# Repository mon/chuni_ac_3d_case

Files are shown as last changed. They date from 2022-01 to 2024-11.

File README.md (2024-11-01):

# Chunithm 3D printed case

This is a 3D printed case so your slider panel + airs you bought off Yahoo
Auctions can happily sit on a table.

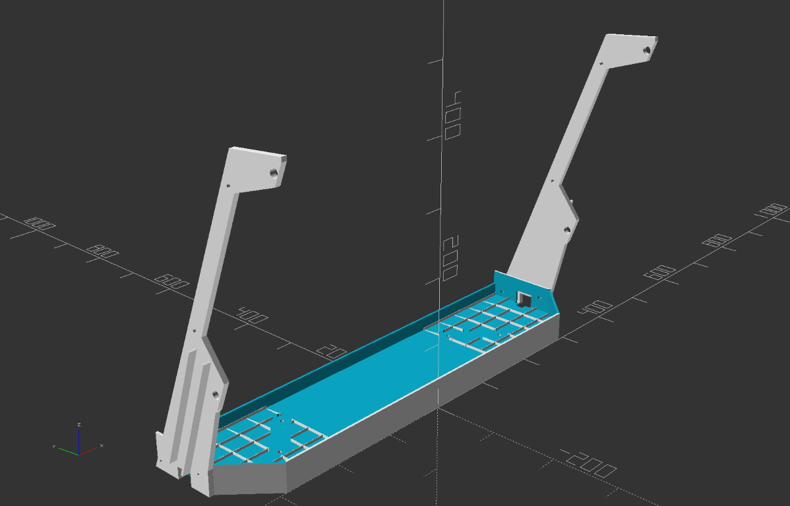
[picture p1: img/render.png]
Render

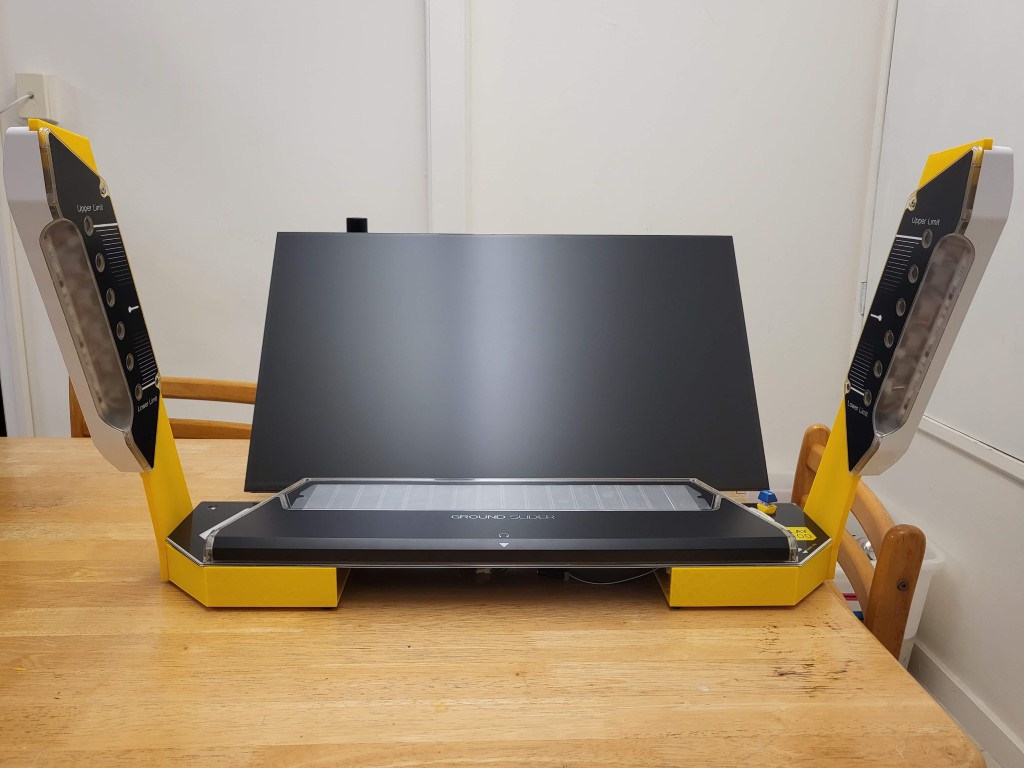
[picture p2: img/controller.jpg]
IRL photo


## Print settings
For all pieces, I used 10% infill, no supports, 0.28mm layer height (Cura's
"Low quality" setting).

## Installation
You will need
- M4 bolt x4, 14mm or longer
- M4 washer x4
- M4 nut x4
- M5 bolt x4, 6mm or longer (these may already exist in the black metal brackets
  the airs were originally attached to)
- Soldering iron or hot object (to press-fit M4 nuts into 3D print)
- About 600g of filament
- 8 rubber adhesive feet

Print all the pieces in the `stl` folder. Ignore `coin_return_cherry_mx` if
you're not going to use it. The `air_bottom` piece will need to be flipped in
your slicer so the flat side is on the bed. Also, mirror `air_bottom` and print
another copy for the opposite air. Ignore `air_bottom` and `air_top` if you want to
lasercut the airs.

Disassemble your air strings, making note of the 2 shorter bolts on the front
side. Put the printed pieces in and reinstall screws. DO NOT OVER-TIGHTEN. The
plastic of the airs may crack if you do. You might need to gently bend the wire
harness to comfortably make it into the wire channel, this is normal.

Using a soldering iron to heat the M4 nuts, carefully push them into the holes on
the case parts. You're not looking for a structural fit, it's just so
the nuts don't fall out.

Attach the rubber feet to the bottom of the case so the screws don't scratch
your table.

You can install the case first or attach the airs to the case first, I prefer
attaching the airs because routing the cable is easier.

Use the M4 bolts and washers to attach the air strings to the case.

Use the M5 bolts to attach the case to the metal bracket on the back of the
slider.

Hook up wiring (see the [wiki](https://rhythm-cons.wiki/w/Chunithm)).

## Notes
- The print is designed for a bed of 300mm, e.g. a CR10s. With some creative
  cutting, it could be fit into a 200mm bed. Feel free to submit a PR if you
  work it out.
- The print contains very large, flat sections directly on the bed. If you don't
  have a flat bed or a mesh bed level, it WILL warp. This can result in
  dimensional inaccuracy (not a huge problem really) or part detachment
  mid-print (quite a problem).
- Some of the holes are off by 0.5-1mm, but it doesn't affect installation. You
  can fix it if you're a perfectionist.

## Thanks
To Moldypie, for the original laser-cut case. The airs would have not existed
without it.

## SCAD notes
It's a mess. Made in a rush, and probably incomprehensible to anyone but me.
Mixture of constants in good places and magic numbers in other places.

Modify `op` at the bottom of the file to render different parts of the build.

Gratuitously use `#` and `%` to debug things if you're trying to extend it.

# Cherry MX adapter for coin return
Bonus!

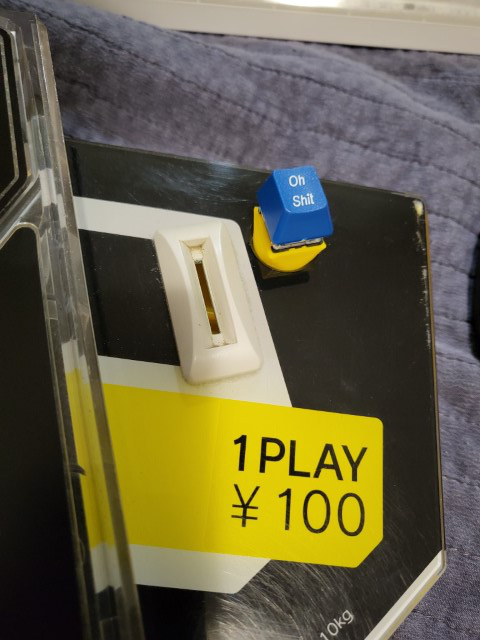
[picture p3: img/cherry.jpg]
Cherry adapter


This lets you replace the coin return button with a Cherry MX switch. Solder
leads to it and pass them through the middle.

I printed this using 0.2mm layer height and used the original nut and washer
to attach it to the metal. It was _extremely_ tight, so I recommend playing with
the tolerances in the thread library if you don't want to get out two spanners
and potentially shatter the piece.

## Lasercuttable Airs

If you don't have a big enough printer or want to make the airs out of another material.

Lasercut `air_lasercut` in the `dxfs` folder with 8mm thick material.
**DO NOT USE** `wall 1_flat` due to bad hole locations.

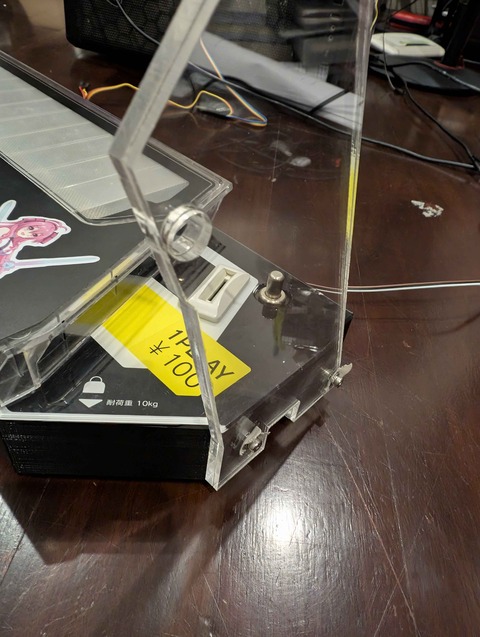
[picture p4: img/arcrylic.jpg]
arcrylic air


I used a combination of 5mm and 3mm arcrylic to make it 8mm thick.

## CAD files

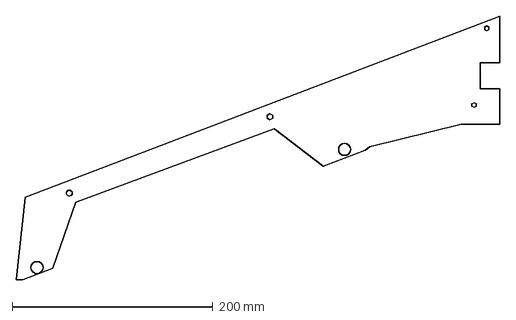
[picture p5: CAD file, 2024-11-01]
dxfs/air_lasercut.dxf
480.8 x 262.2 mm

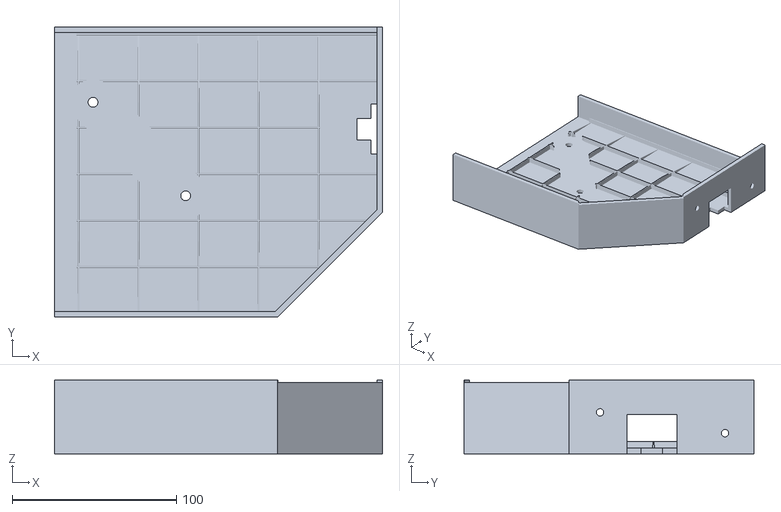
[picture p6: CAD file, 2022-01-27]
stls/case_right.stl
200.0 x 177.0 x 45.1

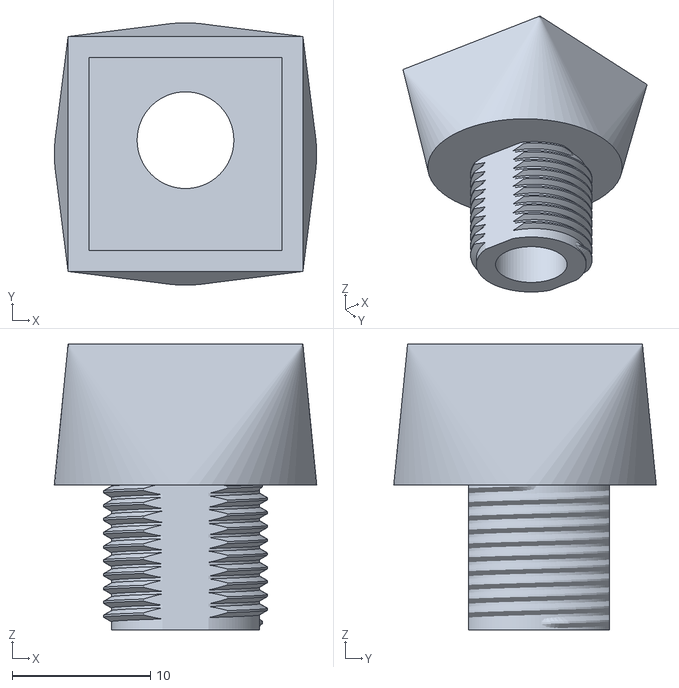
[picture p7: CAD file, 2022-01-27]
stls/coin_return_cherry_mx.stl
19.0 x 19.0 x 20.7

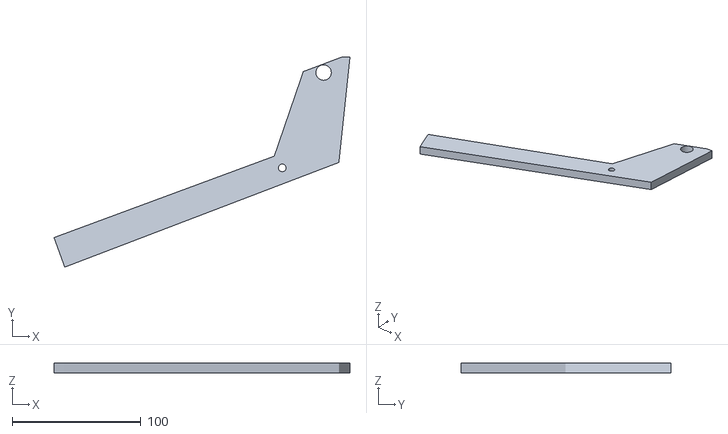
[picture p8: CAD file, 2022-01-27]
stls/air_top.stl
229.7 x 163.2 x 8.00

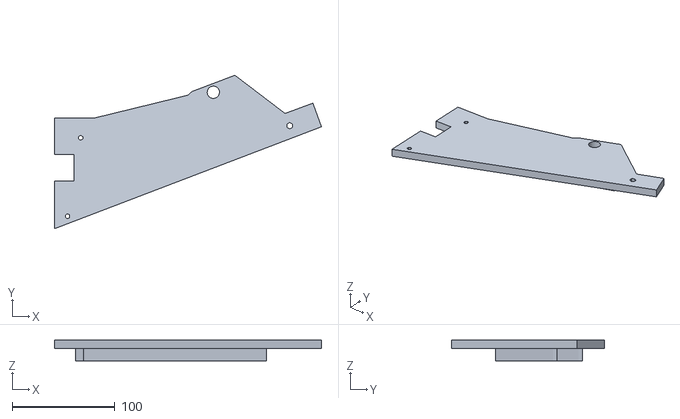
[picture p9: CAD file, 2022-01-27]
stls/air_bottom.stl
259.4 x 149.1 x 20.0

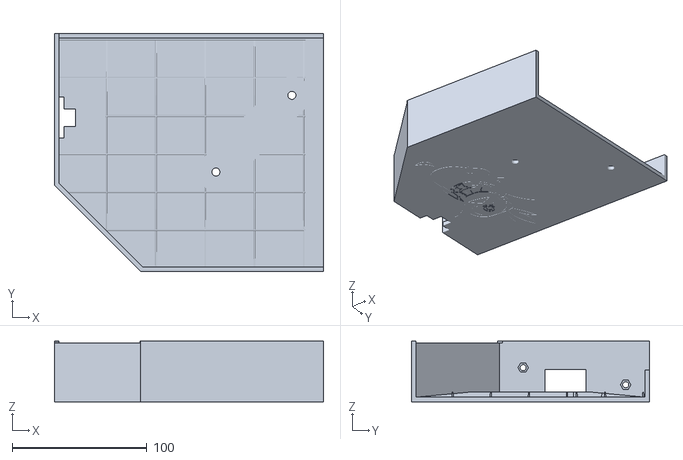
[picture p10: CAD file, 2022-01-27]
stls/case_left.stl
200.0 x 177.0 x 45.1

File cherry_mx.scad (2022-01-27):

$fn=60;
/**
a cherry mx switch.

most of the measurements done with a caliper. some taken from
http://geekhack.org/index.php?topic=47744.0

This is just to illustrate and to drop in a a gross reference. It is mostly artistic apart from the steam and mounting plate dimensions
*/

module cherry_mx_model() {

    translate([0,0,14.85])
    {

        //1. steam
        color("brown"){
            //1.1. l-r tab is 1.35mm
            translate([0,0,-3.62/2])
                cube([1.35,4.5,3.62], center=true);
            //1.2. f-b tab is 1.15mm. it has a smal notch that i will ignore.
            translate([0,0,-3.62/2])
                cube([4.5,1.15,3.62], center=true);
            //1.3. base. it has a chamfered top that i will ignore.
            translate([0,0,-5.62])
                cube([7.2,5.56,4], center=true);
        }
        // 2. top
        color("grey"){
            difference(){
                // make a trapezoid with the general shape (volume?) of the top
                hull(){
                    translate([0,0,-4]) //distance from top of switch... some i measured 3.9 others 4.2... so leaving at 4
                        cube([9.87,10.62,0.1], center=true);
                    translate([0,0,-4 -5.2]) // bottom has a measured 5.3... so move 5.2 and use the 0.1 bellow
                        cube([14.58,14.58,0.1], center=true);
                }

            // and subtract:
            // the front led. NOTE: totally off... measured by eye. just for astetics
            // adding just so there is a visual cue of the direction
                translate([0,-4.7,-6])
                    cylinder(r=3/2, h=6, center=true);
                translate([0,-5.5,-6])
                    cube([8,4,5], center=true);
            // the four corners
                // TODO waste of time? this is all for looks, you shouldn't invade any of that space anyway...
            }
        }

        // 3. bottom
        color("green")
            // 3.1 main body volume
            hull(){
                    translate([0,0,-4 -5.3]) //steam + top
                        cube([13.98,13.98,0.1], center=true);
                    translate([0,0,-4 -5.3 -2.2]) //steam + top + straigth part
                        cube([13.98,13.98,0.1], center=true);
                    translate([0,0,-4 -5.3 -5.5]) //steam + top + bottom (measured 5.5)
                        cube([12.74,13.6,0.1], center=true);
            }
            // 3.2 tabs
            // note: only measured the lenght, if they are slightly off-center, this will be all wrong :)
            color("black")
            difference(){
                translate([0,0,-4 -5.3 -0.82/2]) //steam + top
                    cube([15.64,15.64,0.82], center=true);
                translate([0,0,-4 -5.3 -0.82/2  ]) // front-back cut
                    cube([5.64,20,0.82 +2], center=true);
                translate([0,0,-4 -5.3 -0.82/2  ]) //side cut
                    cube([20,11.64,0.82 +2], center=true);
            }

            // 3.3 tab (plate snap on). to use this mechanically, you have to take into account the bending (as it will move the bottom part slightly up...) just for gross reference here for now
            color("white"){
                // 3.3.1 top
                translate([0,0,-4 -5.3 -0.82/2  ]) // front-back cut
                    cube([1.82,16.33,0.82], center=true);
                // 3.3.2 bottom
                difference(){
                    hull(){
                        translate([0,0,-4 -5.3 -0.82/2 -1.76  ]) // front-back cut
                            cube([3.65,14,0.1], center=true);
                        translate([0,0,-4 -5.3 -0.82/2 -2.2  ]) // front-back cut
                            cube([3.65,14.74,0.1], center=true);
                        translate([0,0,-4 -5.3 -0.82/2 -2.89  ]) // front-back cut
                            cube([3.65,14,0.1], center=true);
                    }
                    translate([0,0,-4 -5.3 -0.82/2 -1.76   ]) // front-back cut
                        cube([2.2,20,4], center=true);

                }
            }

            // 4. bottom guides
            // again, i'm assuming everything is centered...
            color("darkGreen"){
                // 4.1 cylinder
                translate([0,0,-4 -5.3 -5.5 -2/2]) //steam + top + bottom (measured 5.5)
                    cylinder(r=3.85/2, h=2, center=true);
                translate([0,0,-4 -5.3 -5.5 -2 -1/2]) //steam + top + bottom (measured 5.5)
                    cylinder(r2=3.85/2, r1=2.8/2, h=1, center=true);
                // 4.2 PCB pins
                translate([4.95,0,-4 -5.3 -5.5 -2/2]) //steam + top + bottom (measured 5.5)
                    cylinder(r=1.6/2, h=2, center=true);
                translate([4.95,0,-4 -5.3 -5.5 -2 -1/2]) //steam + top + bottom (measured 5.5)
                    cylinder(r2=1.6/2, r1=1/2, h=1, center=true);
                translate([-4.95,0,-4 -5.3 -5.5 -2/2]) //steam + top + bottom (measured 5.5)
                    cylinder(r=1.6/2, h=2, center=true);
                translate([-4.95,0,-4 -5.3 -5.5 -2 -1/2]) //steam + top + bottom (measured 5.5)
                    cylinder(r2=1.6/2, r1=1/2, h=1, center=true);
            }

            // 5. pins
            color("orange"){
                translate([-3.77,2.7,-4 -5.3 -5.5 -3.1/2]) //steam + top + bottom (measured 5.5)
                    cube([.86, 0.2,3.1], center=true);
                translate([2.7,5.2,-4 -5.3 -5.5 -3.1/2]) //steam + top + bottom (measured 5.5)
                    cube([.86, 0.2,3.1], center=true);
            }

    }
}

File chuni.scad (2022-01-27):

$fn=32;

// this makes rendering take like 5 minutes
slow_penguin = true;

// bottom overlap is more like 3.5mm so just be real fuckin
// cheeky and use this for all the walls
wall_thick = 3.5;

acrylic_thick = 3.2;
metal_thick = 1.4;

rib_strength = 1.2;
rib_height = 4;
rib_x = 5;
rib_y = 6;

// for the pengiiiiin
layer_height = 0.28;

con_width = 700;
con_height = 170;
con_depth = 40.5 + acrylic_thick + metal_thick;

// not explicitly for IO but may as well use it
io_hole_x_start = 40;
io_hole_x_end = 135;
io_hole_y_start = 9;
io_hole_y_end = 23;
io_total= 21.5; // the piece of metal itself

height_before_angle = 113;
angle = 45;

overlap_leadin = 5;
side_overlap = 10;
bottom_overlap = 5;
// no top overlap

hole_size = 6; // M5 but I don't trust my hole locations
// y is offset from con top
holes_xy = [
    [116.5, 96],
    [173, 39],
];

air_strings_offset = 10; // from start of `angle`
air_strings_filler = 8; // to stop the plastic cracking
air_strings_wire_channel = 12; // height
// actually 33 but doesn't need to be so big
air_strings_wire_channel_x = 30;
air_strings_angle = 20;
air_holes_normal = 6;
air_holes_bigger = 12; // more like 10mm but whatever

// the screw attaching it to the case
air_strings_screw = 4;
air_strings_attach = [
    [19.05,468.1],
    [19.05*5,455.4],
];
// the nut, [width, depth]
air_strings_nut = [7.8,3];

// mirror, but keeps the original
module reflect(xyz) {
    children();
    mirror(xyz)
    children();
}

module im_gonna_put_holes_in_you(both=true) {
    reflect([both ? 1 : 0,0,0])
    for(hole = holes_xy) {
        translate([
            -con_width/2 + hole.x,
            con_height - hole.y
        ])
        circle(d=hole_size);
    }
}

module main_2d(holes = false) {
    w = con_width+wall_thick*2;
    h = con_height+wall_thick*2;
    
    difference() {
        translate([-w/2,0])
        square([w,h]);
        
        reflect([1,0,0])
        translate([-w/2, h-height_before_angle])
        rotate([0,0,-angle])
        mirror([0,1,0]) // flip it to face down
        square([w,w]);
        
        if(holes) {
            im_gonna_put_holes_in_you();
        }
    }
}

// lots of warping otherwise thanks to the weight of the airs
// and there being only 2 screws to mount the thing
module ribs(height, scale = 1.0) {
    rib_start = [-con_width/2, wall_thick];
    // little past the screws
    rib_end = [
        rib_start.x + holes_xy[1].x + 10,
        rib_start.y + con_height
    ];
    
    sz = [rib_end.x-rib_start.x, rib_end.y-rib_start.y];
    increment = [sz.x/rib_x, sz.y/rib_y];
    
    difference() {
        intersection() {
            linear_extrude(height+0.1)
            main_2d();
            
            linear_extrude(height+0.1)
            translate(rib_start)
            square(sz);
            
            union() {
                for(x = [1:rib_x]) {
                    x_off = x * increment.x + rib_start.x;
                    translate([
                        x_off - rib_strength,
                        rib_start.y + con_height/2])
                    linear_extrude(height, scale=scale)
                    square([rib_strength, con_height], center=true);
                }
                for(y = [1:rib_y]) {
                    y_off = y * increment.y + rib_start.y;
                    translate([
                        rib_start.x,
                        y_off - rib_strength])
                    linear_extrude(height, scale=scale)
                    square([con_width, rib_strength], center=true);
                }
            }
        }
        // avoid the mounting plates
        linear_extrude(height+0.1)
        offset(delta=11)
        hull()
        im_gonna_put_holes_in_you(both=false);
        
        // clear the entry for the wiring
        air_translate()
        linear_extrude(46)
            translate([78.88,480.8])
            rotate([0,0,180])
            // make it bigger than moldy
            square([25.4,19.05] + [5,5]);
    }
}

module main_box(pengy = true) {
    w = con_width+wall_thick*2;
    h = con_height+wall_thick*2;
    
    difference() {
        union() {
            // main box
            difference() {
                linear_extrude(con_depth)
                main_2d(holes = true);
                
                translate([0,0,wall_thick])
                linear_extrude(con_depth)
                offset(delta = -wall_thick)
                main_2d();
            }
            
            // strength
            reflect([1,0,0])
            translate([0,0,wall_thick-0.01])
            ribs(rib_height, scale = 0.5);
        }
        
        translate([0,0,-0.01])
        air_holes();
        
        // cutout the bit at the top since it's flush
        translate([
            -con_width/2,
            con_height+wall_thick/2,
            con_depth - io_total,
        ])
        cube([con_width, wall_thick*2, io_total*2]);
        
        // cutout the angled bits cause the metal goes all
        // the way
        translate([0,0,con_depth - metal_thick])
        linear_extrude(metal_thick*2)
        reflect([1,0,0])
        translate([-w/2, h-height_before_angle])
        rotate([0,0,-angle])
        mirror([0,1,0]) // flip it to face down
        translate([0,-wall_thick*1.5])
        // this is really just eyeballed
        square([90,wall_thick*2]);
        
        if(pengy && slow_penguin) {
            translate([-250,-130,-0.01])
            linear_extrude(layer_height)
            mirror([1,0,0])
            import("Chuni_Penguin.svg");
        }
    }
}

module air_translate() {
    w = con_width+wall_thick*2;
    h = con_height+wall_thick*2;
    
    translate([-w/2, h-height_before_angle])
    rotate([90,-180,90])
    translate([-114.3,-480.8,-air_strings_filler])
    children();
}

module air_translate_2d() {
    rotate([0,0,90])
    translate([0,-480.8])
    children();
}

// this is the left air string, mirror for right
module air() {
    linear_extrude(air_strings_filler)
    difference() {
        union() {
            import("quarter inch/wall 1_flat.svg");
            
            // fill in the old holes
            translate([138,327])
            circle(d=18);
            
            translate([254.5,18.7])
            circle(d=18);
            
            translate([180.2,54.35])
            rotate([0,0,60/2])
            circle(d=7);
            
        }
        
        // moldy hole was wrong
        translate([139.5,326.5])
        circle(d=air_holes_bigger);
        
        translate([254+3,18+2.5])
        circle(d=air_holes_bigger);
        
        translate([183,52.6])
        circle(d=air_holes_normal);
        
        // width is too high for my tastes
        rotate(air_strings_angle+0.9)
        translate([156,-60])
        square([22, 2000]);
    }
    
    // this routes the cable, and also provides some strength
    mirror([0,0,1]) // goes out the back
    linear_extrude(air_strings_wire_channel)
    intersection() {
        import("quarter inch/wall 1_flat.svg"); // clip it
        
        // ugh, has to be tweaked
        rotate([0,0,air_strings_angle-2.4])
        
        difference() {
            base = [184,215];
            l = 200;
            translate(base)
            square([air_strings_wire_channel_x, l]);
            
            translate(base + [wall_thick,0])
            square([air_strings_wire_channel_x-wall_thick*2, l]);
            
            // just lazy cutoff
            translate([0,-100 + 15])
            translate(base)
            square([air_strings_wire_channel_x, 100]);
        }
    }
}

module airs() {
    reflect([1,0,0])
    air_translate()
    air();
}

module air_holes() {
    reflect([1,0,0])
    air_translate()
    linear_extrude(air_strings_filler + wall_thick*2)
    union() {
        for(hole = air_strings_attach) {
            translate(hole)
            circle(d=air_strings_screw+0.5);
        }
        
        translate([78.88,480.8])
        rotate([0,0,180])
        // make it bigger than moldy
        square([25.4,19.05] + [5,5]);
    }
    
    reflect([1,0,0])
    translate([air_strings_filler + (wall_thick-air_strings_nut[1]),0])
    air_translate()
    linear_extrude(air_strings_filler + wall_thick*2)
    union() {
        for(hole = air_strings_attach) {
            translate(hole)
            circle(d=air_strings_nut[0], $fn=6);
        }
    }
    
    // extra bit in case your connector goes in upside down
    reflect([1,0,0])
    translate([con_width/2,108])
    mirror([1,0,0])
    cube([12,13,con_depth]);
}

// so it fits on the printer
module air_splitter() {
    translate([0,0,-500])
    linear_extrude(1000)
    rotate([0,0,air_strings_angle])
    translate([0,-150])
    square([280,300]);
}

op = "render";
//op = "air";
//op = "air_top";
//op = "air_bottom";
//op = "case_left";
//op = "case_right";

//op = "";
//ribs();
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

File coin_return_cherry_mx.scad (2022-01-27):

use <cherry_mx.scad>
// https://github.com/adrianschlatter/threadlib
use <threadlib/threadlib.scad>

stl = true;

$fn = 64;

hole_d = 12;
hole_flat = 11;
metal_thick = 1.4;
acrylic_d = 20 - 1;
// the hole in the acrylic is off center, this is what the orig uses
button_d = 16;

min_clearance = 3; // the switch is bigger than acrylic_d

interface = 2;

// little higher than metal just for clearance
raise = 0.2;

// must be at least 5 or switch collides
switch_height = 8 + raise + interface;

module switch_hole(expansion = false) {
    // from Cherry MX data sheet
    holesize = 14;

    translate([-holesize/2, -holesize/2])
    square([holesize,holesize]);

    // expansion for inner layers so the clips have something to grab
    if(expansion) {
        expand_hole = [5, 15];
        translate(-expand_hole/2)
        square(expand_hole);
    }
}

module plate() {
    translate([0,0,-metal_thick])
    linear_extrude(metal_thick)
    difference() {
        square([50,50], center=true);
        
        intersection() {
            circle(d=hole_d);
            square([hole_d, hole_flat], center=true);
        }
    }
}


module thread() {
    height = 50; // tune depending on turns
    
    rotate([180,0,0])
    difference() {
        intersection() {
            bolt("M12x0.75", turns=10);
            
            linear_extrude(height)
            square([hole_d, hole_flat-0.8], center=true);
        }
        
        // for switch wires to get through
        translate([0,0,-0.01])
        cylinder(height, d=7);
    }
}

if(!stl)
%plate();

need_d = 2 * sqrt(2 * 7*7) + min_clearance;
top_d = (need_d > acrylic_d) ? need_d : acrylic_d;

// off center cutout
translate([0,-1]) {
    if(!stl)
    translate([0,0,switch_height - 5])
    cherry_mx_model();
    
    difference() {
        hull() {
            linear_extrude(0.01)
            circle(d=acrylic_d);
            
            translate([0,0,switch_height - 0.01])
            linear_extrude(0.01)
            square(14+min_clearance, center=true);
        }
        //cylinder(h=switch_height, d1=acrylic_d, d2=top_d);
        
        translate([0,0,interface-0.01])
        linear_extrude(switch_height+0.02)
        switch_hole();
        
        translate([0,0,switch_height-3])
        // should be -1 but give us plenty
        linear_extrude((switch_height-0.8)-(switch_height-3))
        switch_hole(expansion=true);
        
        translate([0,1,-0.01])
        cylinder(h=interface+1, d=7);
    }
}

thread();

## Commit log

2022-01-27 Specify bolt lengths
2024-11-01 added lasercut airs section (#1)
    * added lasercut info
    * Add files via upload
    * Update README.md
    * Create folder
    * Add files via upload
    * Delete quarter inch/dxfs directory
    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
    [air_lasercut.dxf]
